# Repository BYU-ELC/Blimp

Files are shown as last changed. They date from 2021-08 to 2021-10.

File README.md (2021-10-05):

# Air Blimp
Sources, code, and files for the Air Blimp project

This code is implemented as a Bluetooth app. 
A helium balloon will keep the blimp suspended in air. This Bluetooth app will have access to the vector thrusters on either side, and when signified, these will steer the blimp in the desired direction.

This main  folder includes:
<br>The PCB Schematic File:     Blimp PCB v27.sch
<br>The PCB Board File:         Blimp_PCB_v50.brd
<br>The Laser cut vector file:  blimp_cut_v3.dxf
<br>The Arduino Code:           blimp.ino

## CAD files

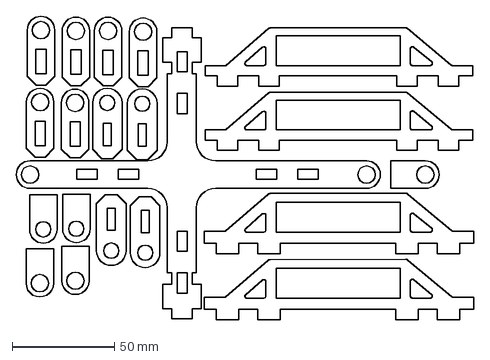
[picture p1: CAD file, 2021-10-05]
blimp cut v3.dxf
223.7 x 148.3 mm

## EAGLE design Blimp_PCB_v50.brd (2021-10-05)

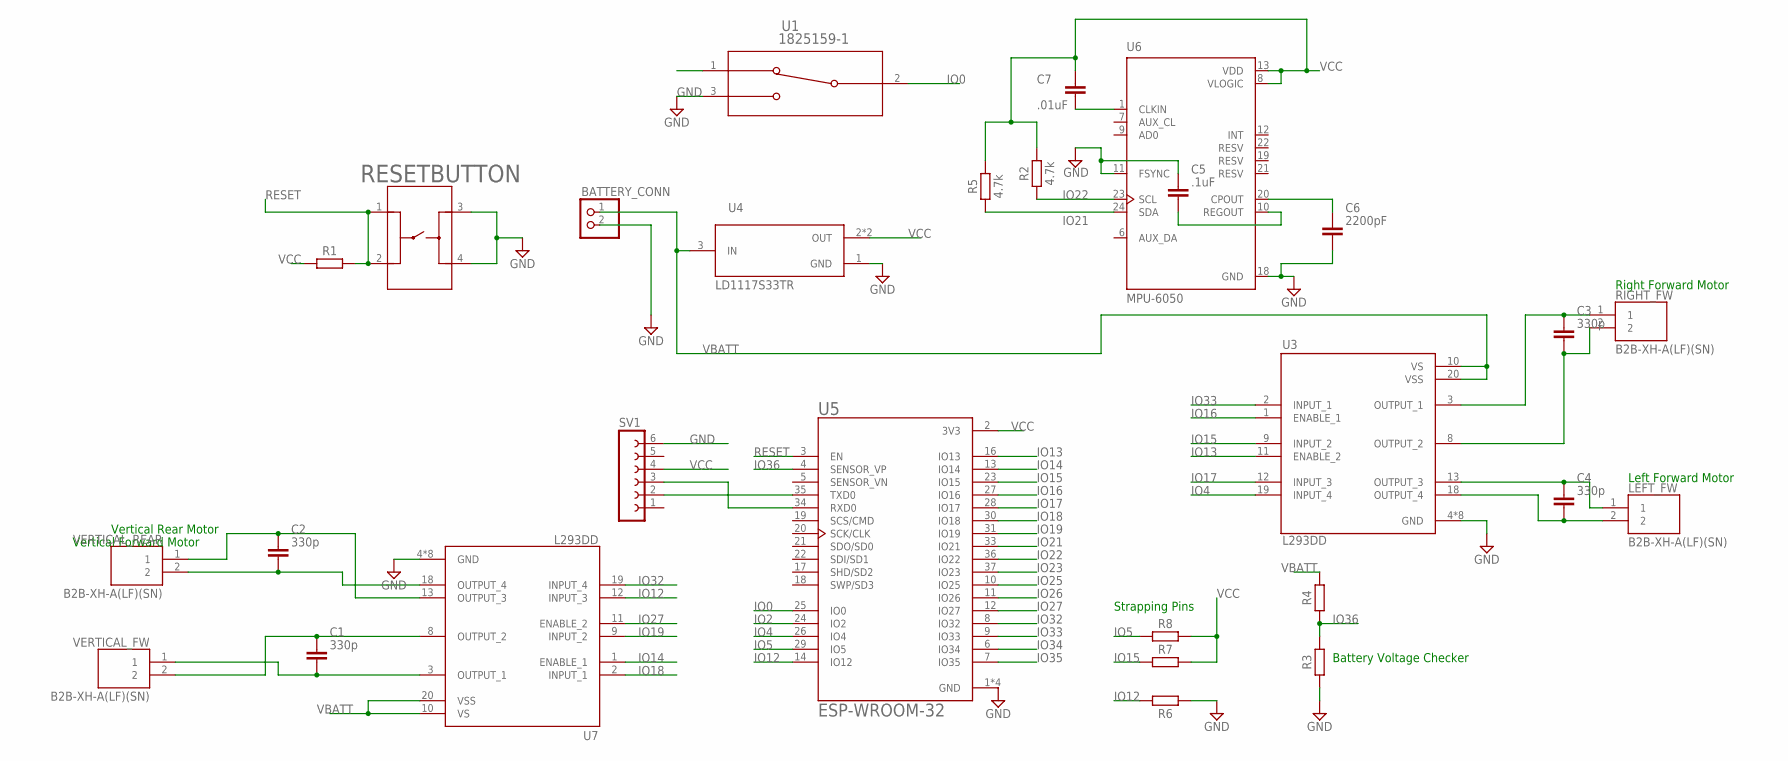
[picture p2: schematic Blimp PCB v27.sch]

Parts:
BATTERY_CONN: PINHD-1X2; 1X02
C1, C2, C3, C4: 330p; CAPC1005X60
C5: .1uF; CAPC2012X110
C6: 2200pF; CAPC2012X110
C7: .01uF; CAPC2012X110
LEFT_FW: B2B-XH-A(LF)(SN); JST_B2B-XH-A(LF)(SN)
R1, R6, R7, R8: R_CHIP-1206(3216-METRIC); RESC3216X70
R2, R5: 4.7k; RESC3216X70
R3, R4: R_CHIP-0603(1608-METRIC); RESC1608X60
RESETBUTTON: 1-1825910-0; SWITCH_1-1825910-0
RIGHT_FW: B2B-XH-A(LF)(SN); JST_B2B-XH-A(LF)(SN)
SV1: FE06-1; FE06
U1: 1825159-1; SW3-SLIDE-2POL_P98
U3, U7: L293DD; SOIC127P1032X265-20N
U4: LD1117S33TR; SOT230P700X180-4N
U5: ESP-WROOM-32; MODULE_ESP-WROOM-32
U6: MPU-6050; QFN50P400X400X95-24N
VERTICAL_FW: B2B-XH-A(LF)(SN); JST_B2B-XH-A(LF)(SN)
VERTICAL_REAR: B2B-XH-A(LF)(SN); JST_B2B-XH-A(LF)(SN)

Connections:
GND: BATTERY_CONN.2, C5.1, C6.2, R3.1, R6.1, RESETBUTTON.3, RESETBUTTON.4, SV1.6, U1.3 (2), U3.4 (GND), U3.5 (GND), U3.6 (GND), U3.7 (GND), U3.14 (GND), U3.15 (GND), U3.16 (GND), U3.17 (GND), U4.1 (GND), U5.1 (GND), U5.1.1 (GND), U5.15 (GND), U5.38 (GND), U6.11 (FSYNC), U6.18 (GND), U7.4 (GND), U7.5 (GND), U7.6 (GND), U7.7 (GND), U7.14 (GND), U7.15 (GND), U7.16 (GND), U7.17 (GND)
IO0: U1.2 (3), U5.25 (IO0)
IO2: U5.24 (IO2)
IO4: U3.19 (INPUT_4), U5.26 (IO4)
IO5: R8.1, U5.29 (IO5)
IO12: R6.2, U5.14 (IO12), U7.12 (INPUT_3)
IO13: U3.11 (ENABLE_2), U5.16 (IO13)
IO14: U5.13 (IO14), U7.1 (ENABLE_1)
IO15: R7.1, U3.9 (INPUT_2), U5.23 (IO15)
IO16: U3.1 (ENABLE_1), U5.27 (IO16)
IO17: U3.12 (INPUT_3), U5.28 (IO17)
IO18: U5.30 (IO18), U7.2 (INPUT_1)
IO19: U5.31 (IO19), U7.9 (INPUT_2)
IO21: R5.1, U5.33 (IO21), U6.24 (SDA)
IO22: R2.1, U5.36 (IO22), U6.23 (SCL)
IO23: U5.37 (IO23)
IO25: U5.10 (IO25)
IO26: U5.11 (IO26)
IO27: U5.12 (IO27), U7.11 (ENABLE_2)
IO32: U5.8 (IO32), U7.19 (INPUT_4)
IO33: U3.2 (INPUT_1), U5.9 (IO33)
IO34: U5.6 (IO34)
IO35: U5.7 (IO35)
IO36: R3.2, R4.1, U5.4 (SENSOR_VP)
unnamed: C3.1, RIGHT_FW.1, U3.3 (OUTPUT_1)
unnamed: C3.2, RIGHT_FW.2, U3.8 (OUTPUT_2)
unnamed: C4.1, LEFT_FW.1, U3.13 (OUTPUT_3)
unnamed: C1.1, U7.8 (OUTPUT_2), VERTICAL_FW.2
unnamed: C1.2, U7.3 (OUTPUT_1), VERTICAL_FW.1
unnamed: C2.1, U7.13 (OUTPUT_3), VERTICAL_REAR.1
unnamed: C2.2, U7.18 (OUTPUT_4), VERTICAL_REAR.2
unnamed: SV1.2, U5.35 (TXD0)
unnamed: C6.1, U6.20 (CPOUT)
unnamed: C5.2, U6.10 (REGOUT)
unnamed: C7.2, U6.1 (CLKIN)
unnamed: C4.2, LEFT_FW.2, U3.18 (OUTPUT_4)
unnamed: SV1.3, U5.34 (RXD0)
RESET: R1.2, RESETBUTTON.1, RESETBUTTON.2, U5.3 (EN)
VBATT: BATTERY_CONN.1, R4.2, U3.10 (VS), U3.20 (VSS), U4.3 (IN), U7.10 (VS), U7.20 (VSS)
VCC: C7.1, R1.1, R2.2, R5.2, R7.2, R8.2, SV1.4, U4.2 (OUT), U4.4 (OUT), U5.2 (3V3), U6.8 (VLOGIC), U6.13 (VDD)

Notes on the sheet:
Battery Voltage Checker
Right Forward Motor
Left Forward Motor
Vertical Forward Motor
Vertical Rear Motor
Strapping Pins

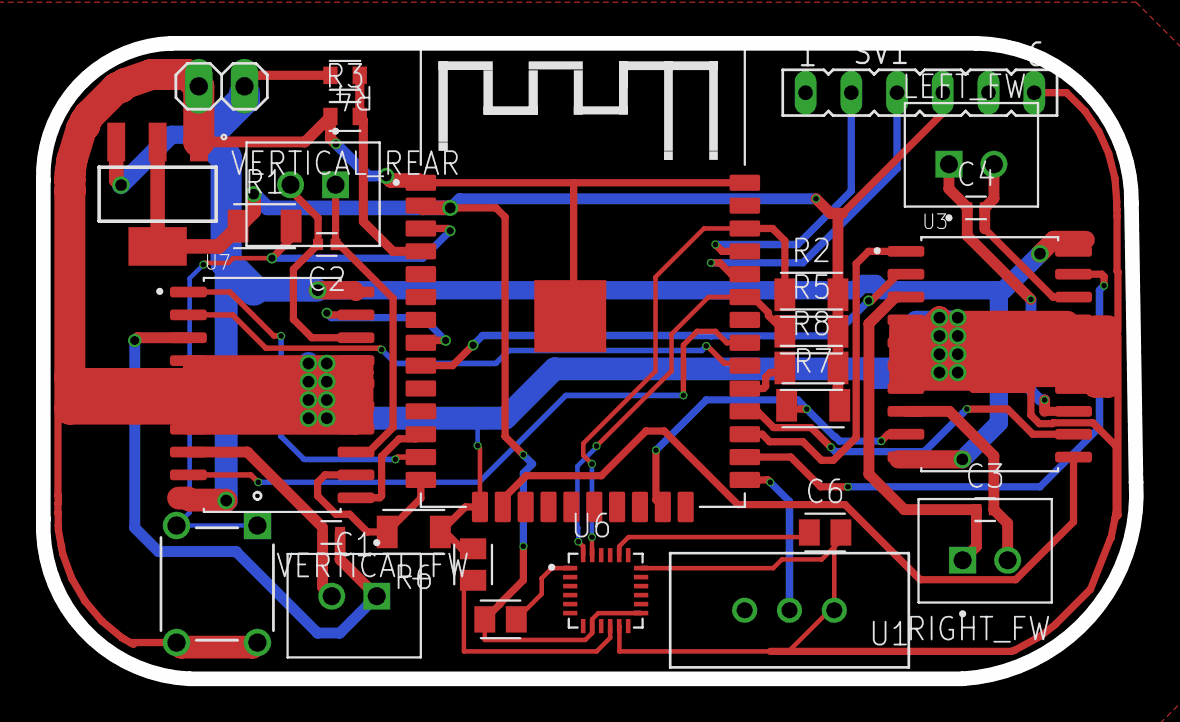
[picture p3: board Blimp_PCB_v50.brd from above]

Board: 2 copper layers, 60.7 x 35.3 mm, 28 parts (0 on the bottom side), 34 nets.

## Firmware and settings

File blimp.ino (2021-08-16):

//This example code is in the Public Domain (or CC0 licensed, at your option.)
//By Evandro Copercini - 2018
//
//This example creates a bridge between Serial and Classical Bluetooth (SPP)
//and also demonstrate that SerialBT have the same functionalities of a normal Serial

#include "BluetoothSerial.h"
#include "I2Cdev.h"
#include "MPU6050.h"
#include "string.h"
#include "math.h"


#if !defined(CONFIG_BT_ENABLED) || !defined(CONFIG_BLUEDROID_ENABLED)
#error Bluetooth is not enabled! Please run `make menuconfig` to and enable it
#endif

BluetoothSerial SerialBT;


//Each motor has three GPIO pins, input1 and input2 control the direction the motor is spinning and enable is a PWM pin that controls horizontalSpeed

//Pin numbers for forward facing right motor
const int forward_right_enablePin = 16;
const int foward_right_input1 = 33;
const int foward_right_input2 = 15;
const int forward_right_pwmChannel = 0;

//Pin numbers for forward facing left motor
const int forward_left_enablePin = 13;
const int foward_left_input1 = 17;
const int foward_left_input2 = 4;
const int forward_left_pwmChannel = 1;


//Pin numbers for vertical forward motor
const int vertical_forward_enablePin = 14;
const int vertical_forward_input1 = 18;
const int vertical_forward_input2 = 19;
const int vertical_forward_pwmChannel = 2;


//pin numberfs for vertical rear motor
const int vertical_rear_enablePin = 27;
const int vertical_rear_input1 = 12;
const int vertical_rear_input2 = 32;
const int vertical_rear_pwmChannel = 3;

//pin numbers for voltage detection
const int battery_voltage = 36;
int voltage = 0;
float voltageMovingAverage = 4.2;

//pin numbers for accelerometer data



// Setting PWM properties
const int freq = 30000;
const int resolution = 8;




int turn = 0;
int horizontalSpeed = 0;
int verticalSpeed = 0;


//Bluetooth app setup
int update_interval=100; // time interval in ms for updating panel indicators 
unsigned long last_time=0; // time of last update
bool connectedFlag = false;
int timeRemaining = 10;
int fuelRemaining = 100;

//Keyed Entry
char dataIn;
String passkey = "";
String code = "1234";


//Accelerometer Setup

// Arduino Wire library is required if I2Cdev I2CDEV_ARDUINO_WIRE implementation
// is used in I2Cdev.h
#if I2CDEV_IMPLEMENTATION == I2CDEV_ARDUINO_WIRE
    #include "Wire.h"
#endif

// class default I2C address is 0x68
// specific I2C addresses may be passed as a parameter here
// AD0 low = 0x68 (default for InvenSense evaluation board)
// AD0 high = 0x69
//MPU6050 accelgyro;
MPU6050 accelgyro(0x69); // <-- use for AD0 high

int16_t ax, ay, az;
int16_t gx, gy, gz;



// uncomment "OUTPUT_READABLE_ACCELGYRO" if you want to see a tab-separated
// list of the accel X/Y/Z and then gyro X/Y/Z values in decimal. Easy to read,
// not so easy to parse, and slow(er) over UART.
#define OUTPUT_READABLE_ACCELGYRO

// uncomment "OUTPUT_BINARY_ACCELGYRO" to send all 6 axes of data as 16-bit
// binary, one right after the other. This is very fast (as fast as possible
// without compression or data loss), and easy to parse, but impossible to read
// for a human.
//#define OUTPUT_BINARY_ACCELGYRO





//horizontalSpeed is the forward velocity of the blimp, an integer from -255-255
//turn is the amount the vehichle will turn -255-255
void moveBlimpHorizontal(int horizontalSpeed, int turn) {

  int righthorizontalSpeed = horizontalSpeed + turn/2;
  int lefthorizontalSpeed = horizontalSpeed - turn/2;
  
  if(lefthorizontalSpeed > 255) {
    lefthorizontalSpeed = 255;
  }
  if(righthorizontalSpeed > 255) {
    righthorizontalSpeed = 255;
  }
  if(lefthorizontalSpeed < -255) {
    lefthorizontalSpeed = -255;
  }
    if(righthorizontalSpeed < -255) {
    righthorizontalSpeed = -255;
  }

  Serial.print("Right: "); Serial.println(righthorizontalSpeed);
  Serial.print("Left: "); Serial.println(lefthorizontalSpeed);
  
  if(righthorizontalSpeed < 0 ) {
    digitalWrite(foward_right_input1,HIGH);
    digitalWrite(foward_right_input2,LOW);
    ledcWrite(forward_right_pwmChannel, -righthorizontalSpeed);
  }
  
  else if(righthorizontalSpeed > 0) {
    Serial.println(turn);
    digitalWrite(foward_right_input1,LOW);
    digitalWrite(foward_right_input2,HIGH);
    ledcWrite(forward_right_pwmChannel, righthorizontalSpeed);

  }

  if(lefthorizontalSpeed < 0){
    digitalWrite(foward_left_input1,HIGH);
    digitalWrite(foward_left_input2,LOW);
    ledcWrite(forward_left_pwmChannel, -lefthorizontalSpeed);
   }
  else if(lefthorizontalSpeed > 0) {
    digitalWrite(foward_left_input1,LOW);
    digitalWrite(foward_left_input2,HIGH);
    ledcWrite(forward_left_pwmChannel, lefthorizontalSpeed);
   }

  //if the horizontalSpeed of both motors is 0 disable the motors
  if(righthorizontalSpeed == 0) {
    digitalWrite(foward_right_input1,LOW);
    digitalWrite(foward_right_input2,LOW);
    
  }

  if(lefthorizontalSpeed == 0) {
    digitalWrite(foward_left_input1,LOW);
    digitalWrite(foward_left_input2,LOW);
  }
}


void moveBlimpVertical(int verticalSpeed) {
  Serial.println(verticalSpeed);
  if(verticalSpeed > 0) {
    digitalWrite(vertical_forward_input1,LOW);
    digitalWrite(vertical_forward_input2,HIGH);
    ledcWrite(vertical_forward_pwmChannel, verticalSpeed);
    digitalWrite(vertical_rear_input1,LOW);
    digitalWrite(vertical_rear_input2,HIGH);
    ledcWrite(vertical_rear_pwmChannel, verticalSpeed);
  }
  else if(verticalSpeed < 0) {
    digitalWrite(vertical_forward_input1,HIGH);
    digitalWrite(vertical_forward_input2,LOW);
    ledcWrite(vertical_forward_pwmChannel, verticalSpeed);
    digitalWrite(vertical_rear_input1,HIGH);
    digitalWrite(vertical_rear_input2,LOW);
    ledcWrite(vertical_rear_pwmChannel, verticalSpeed);
  }
  
  else {
    digitalWrite(vertical_forward_input1,LOW);
    digitalWrite(vertical_forward_input2,LOW);

    digitalWrite(vertical_rear_input1,LOW);
    digitalWrite(vertical_rear_input2,LOW);

  }
}


void setup() {
  Serial.begin(115200);

  SerialBT.begin("Blimp"); //Bluetooth device name
  Serial.println("The device started, now you can pair it with bluetooth!");


  pinMode(forward_right_enablePin,OUTPUT);
  pinMode(foward_right_input1,OUTPUT);
  pinMode(foward_right_input2,OUTPUT);
  
  pinMode(forward_left_enablePin,OUTPUT);
  pinMode(foward_left_input1,OUTPUT);
  pinMode(foward_left_input2,OUTPUT);

  pinMode(vertical_forward_enablePin,OUTPUT);
  pinMode(vertical_forward_input1,OUTPUT);
  pinMode(vertical_forward_input2,OUTPUT);

  pinMode(vertical_rear_enablePin,OUTPUT);
  pinMode(vertical_rear_input1,OUTPUT);
  pinMode(vertical_rear_input2,OUTPUT);

  pinMode(battery_voltage,INPUT);


    // configure LED PWM functionalitites
  ledcSetup(forward_right_pwmChannel, freq, resolution);
  ledcSetup(forward_left_pwmChannel, freq, resolution);
  ledcSetup(vertical_forward_pwmChannel, freq, resolution);
  ledcSetup(vertical_rear_pwmChannel, freq, resolution);

  
  
  // attach the channel to the GPIO to be controlled
  ledcAttachPin(forward_right_enablePin, forward_right_pwmChannel);
  ledcAttachPin(forward_left_enablePin, forward_left_pwmChannel);
  ledcAttachPin(vertical_forward_enablePin, vertical_forward_pwmChannel);
  ledcAttachPin(vertical_rear_enablePin, vertical_rear_pwmChannel);


  

  //  bluetooth app setup
  while(!connectedFlag)
{
  voltage = analogRead(battery_voltage);
  float voltageFloat = voltage * (6.6 / 4095);
  String voltageToReport = "*F";
  voltageToReport = voltageToReport + voltageFloat + "*";
  SerialBT.println(voltageToReport);


  
  SerialBT.println("*.kwl");
  SerialBT.println("clear_panel()");
  SerialBT.println("set_grid_size(17,8)");
  SerialBT.println("add_text(8,3,xlarge,C,Please enter the flight code:,245,240,245,)");
  SerialBT.println("add_send_box(6,5,5,,C,E)");
  SerialBT.println("add_accelerometer(5,5,1,100,A,*)");
  SerialBT.println("set_panel_notes(-,,,)");
  SerialBT.println("run()");
  SerialBT.println("*");
  delay(1000);
  if(SerialBT.available())
  {
    while(!passkey.equals(code))
    {
      dataIn = SerialBT.read();
     
      if(dataIn == 'C')
      {
        passkey = "";
        while(dataIn != 'E')
        {
          if(SerialBT.available())
          {
            dataIn = SerialBT.read();
            Serial.println(dataIn);
            if(dataIn != 'E') passkey += dataIn;
          }
        }
      }
    }

    connectedFlag = true;
    SerialBT.println("*.kwl");
    SerialBT.println("clear_panel()");
    SerialBT.println("set_grid_size(17,8)");
    SerialBT.println("add_text(3,1,xlarge,L,  Time,245,240,245,)");
    SerialBT.println("add_text(12,1,xlarge,L,  Fuel,245,240,245,)");
    SerialBT.println("add_free_pad(13,4,0,100,0,100,R,)");
    SerialBT.println("add_free_pad(1,4,0,100,0,0,L,)");
    SerialBT.println("add_gauge(10,2,4,300,450,365,F,3,4.5,3,5)");
    SerialBT.println("add_gauge(1,2,4,0,10,0,T,,,10,5)");
    SerialBT.println("add_text(8,5,xlarge,C,,245,0,0,E)");
    SerialBT.println("add_xy_graph(7,0,3,-100.0,100.0,-100.0,100.0,5,H,,Pitch,Roll,0,0,0,0,1,1,0,0,0,none,large,1,1,42,97,222)");
    SerialBT.println("set_panel_notes(,,,)");
    SerialBT.println("run()");
    SerialBT.println("*");
    Serial.println("Setup complete");
    delay(1000);
  }
}


//Accelerometer Setup

// join I2C bus (I2Cdev library doesn't do this automatically)
    #if I2CDEV_IMPLEMENTATION == I2CDEV_ARDUINO_WIRE
        Wire.begin();
    #elif I2CDEV_IMPLEMENTATION == I2CDEV_BUILTIN_FASTWIRE
        Fastwire::setup(400, true);
    #endif

    // initialize device
    Serial.println("Initializing I2C devices...");
    accelgyro.initialize();

    // verify connection
    Serial.println("Testing device connections...");
    Serial.println(accelgyro.testConnection() ? "MPU6050 connection successful" : "MPU6050 connection failed");

    // use the code below to change accel/gyro offset values
    
    Serial.println("Updating internal sensor offsets...");
    // -76  -2359 1688  0 0 0
    accelgyro.setXAccelOffset(473);
    accelgyro.setYAccelOffset(-3973);
    accelgyro.setZAccelOffset(1325);
    accelgyro.setXGyroOffset(142);
    accelgyro.setYGyroOffset(12);
    accelgyro.setZGyroOffset(26);


  
  // testing
  Serial.print("Testing DC Motor...");
}

void loop() {

  if (SerialBT.available()) {

    char temp = SerialBT.read();
    // Serial.write(temp);
    if (temp == 'L'){
      if (SerialBT.read() == 'X'){
        char c;
        String num = "";
        while(isdigit((c = SerialBT.read()))) {
   
          num += c;
         
        }
       
        int Xval = num.toInt();
        turn = map(Xval,0,100,-255,255);

       
        num = "";
        while(isdigit((c = SerialBT.read()))) {
   
          num += c;
         
        }
        int Yval = num.toInt();
        verticalSpeed = map(Yval, 0, 100, -255, 255);

       
      }
    }
    else {
      if (SerialBT.read() == 'X'){
        char c;
        String num = "";
        while(isdigit((c = SerialBT.read()))) {
   
          num += c;
         
        }
       
        int Xval = num.toInt();


       
        num = "";
        while(isdigit((c = SerialBT.read()))) {
   
          num += c;
         
        }
        int Yval = num.toInt();
        horizontalSpeed = map(Yval,0,100,-255,255);

       
      }
    }
   
   
  }

//  }

// read raw accel/gyro measurements from device
  accelgyro.getMotion6(&ax, &ay, &az, &gx, &gy, &gz);

    // these methods (and a few others) are also available
    //accelgyro.getAcceleration(&ax, &ay, &az);
    //accelgyro.getRotation(&gx, &gy, &gz);
  float axg,ayg,azg;


        // display tab-separated accel/gyro x/y/z values
  axg = (5.9814*pow(10,-4)) * ax + 2.1984*pow(10,-16);
  ayg = (5.9814*pow(10,-4)) * ay + 2.1984*pow(10,-16);
  azg = (5.9814*pow(10,-4)) * az + 2.1984*pow(10,-16);
  Serial.print("a/g:\t");
  Serial.print(axg); Serial.print("\t");
  Serial.print(ayg); Serial.print("\t");
  Serial.print(azg); Serial.print("\t");
  Serial.print(gx); Serial.print("\t");
  Serial.print(gy); Serial.print("\t");
  Serial.println(gz);

  float deltaP = acos(azg/11) * 180/3.14;
  float deltaR = asin(axg/19.6) * 180/3.14;

  Serial.print("Pitch: "); Serial.println(deltaP);
  Serial.print("Roll: "); Serial.println(deltaR);
  
  String mpuData = "*HX";
  mpuData = mpuData + deltaR + "Y" + deltaP + "*";
  SerialBT.println(mpuData);

  moveBlimpHorizontal(horizontalSpeed,turn);
  moveBlimpVertical(verticalSpeed);

  
  voltage = analogRead(battery_voltage);
  float voltageFloat = (voltage * 660) / 4095;
  voltageMovingAverage = (7 * voltageFloat + voltageMovingAverage)/8;
  int voltageInt = round(voltageFloat) + 20;
  String voltageToReport = "*F";
  voltageToReport = voltageToReport + voltageInt + "*";
  SerialBT.println(voltageToReport);
  if(voltageInt <= 340)
  {
    SerialBT.println("*ETime to Land*");
  }
  else{
    SerialBT.println("*E*");
  }
//  delay(20);
}

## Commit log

2021-06-01 added vertical motor control
2021-06-02 Update blimp.ino
    Added imu sensor reading
2021-06-02 Update blimp.ino
    Readded Accelerometer code
2021-06-02 updated gpio pin number
2021-06-09 Update blimp.ino
    Fixed the app so that the password you type in doesn't disappear quickly.
    [blimp.ino]
2021-08-16 Updated changes to include sending of battery voltage to the app
2021-10-05 Delete Blimp_PCB_v31.brd
    This is outdated
    [Blimp_PCB_v31.brd]
2021-10-05 Delete Blimp_PCB_v19.sch
    outdated
    [Blimp_PCB_v19.sch]
2021-10-05 Add files via upload
    These are the final versions as of the end of summer 2021.
    [Blimp PCB v27.sch, Blimp_PCB_v50.brd]

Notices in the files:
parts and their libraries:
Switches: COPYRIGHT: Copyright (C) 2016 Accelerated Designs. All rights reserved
